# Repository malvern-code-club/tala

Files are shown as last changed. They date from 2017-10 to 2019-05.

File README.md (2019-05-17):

# Tala



A text only portable communication device designed for an apocolypse. This project was a competition entry for [Raspberry Pi Pioneers](https://www.raspberrypi.org/pioneers/).

> Our project ended up winning **'Best Explaination'**. Check out the [announcement blog post](https://www.raspberrypi.org/blog/pioneers-winners-only-you-can-save-us/) ([archive.org](https://web.archive.org/web/20180103014359/https://www.raspberrypi.org/blog/pioneers-winners-only-you-can-save-us/)) for the other winning projects.

> The repository as of when the competition was taking place can be seen on the [`final` tag](https://github.com/malvern-code-club/tala/tree/final).

## talalib.py

talalib.py is a Python module to interact with *most* of the sensors in the Tala
project. You can read the documentation for this module [here](talalib.md).

## Wiring

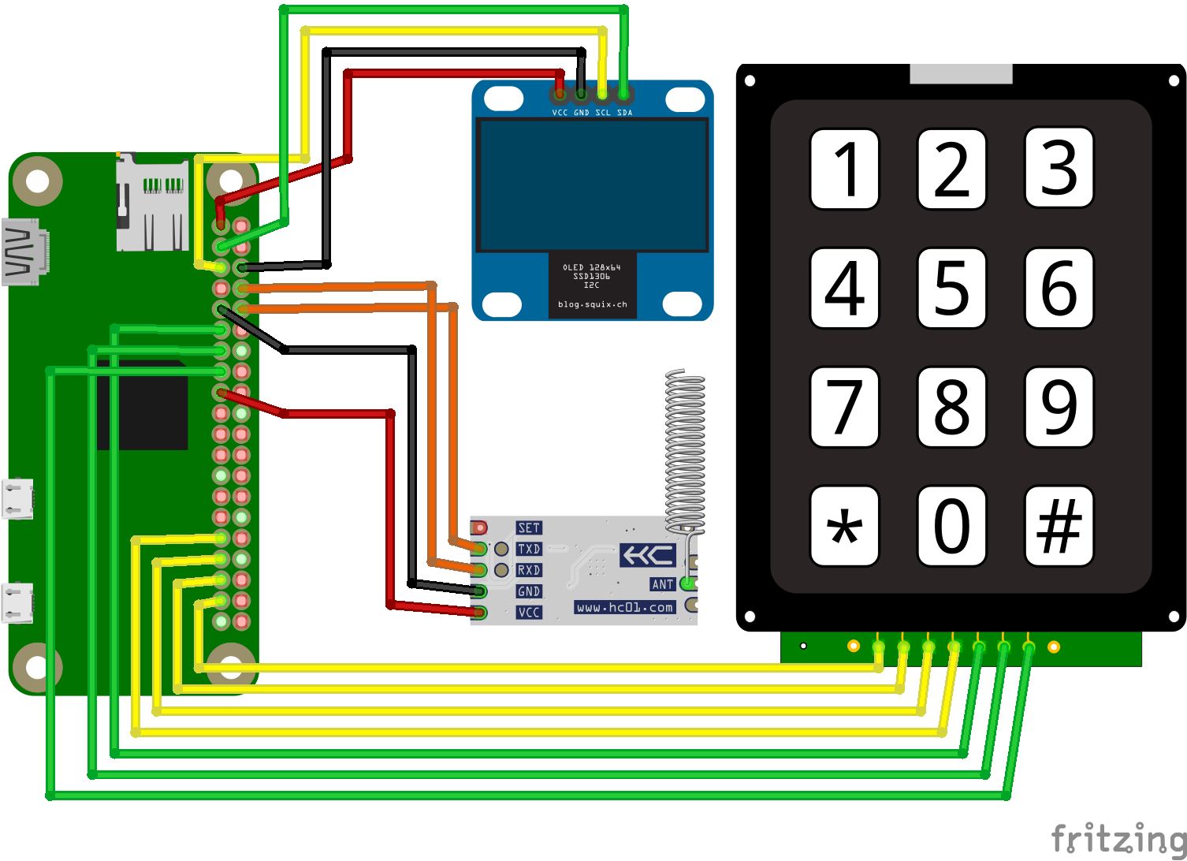
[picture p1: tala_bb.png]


***Wiring for modules may not be as they show in this diagram! We bought 2 OLED
screens and the pinouts on both are different. Be careful!***

### Screen

| Screen | Raspberry Pi |
| --- | --- |
| VCC | 3v3 *(Pin 1)* |
| GND | Ground *(Pin 6)* |
| SCL | SCL *(Pin 5)* |
| SDA | SDA *(Pin 3)* |

### Keypad

| Keypad | Raspberry Pi |
| --- | --- |
| Row 1  | BCM 26 *(Pin 37)* |
| Row 2  | BCM 19 *(Pin 35)* |
| Row 3  | BCM 13 *(Pin 33)* |
| Row 4  | BCM 6 *(Pin 31)*  |
| Col 1  | BCM 17 *(Pin 11)* |
| Col 2  | BCM 27 *(Pin 13)* |
| Col 3  | BCM 22 *(Pin 15)* |

### HC-12 Module

| HC-12 | Raspberry Pi |
| ----- | --- |
| VCC | 3v3 *(Pin 17)* |
| GND | Ground *(Pin 9)*  |
| RXD | BCM 14 *(Pin 8)*  |
| TXD | BCM 15 *(Pin 10)* |

## Installation

1. Start by flashing the latest Raspbian Lite onto an SD card.
2. After it has booted type `sudo raspi-config` to bring up a configuration
window, select `Interfacing Options` -> `I2C` -> `Yes`, then `Interfacing Options`
-> `Serial` -> `No` -> `Yes`. **Rebooting now is not required as we will do it
in the 4th step.**
3. Setup a Wi-Fi connection (you can skip this if you are using ethernet) by
editing this file with the command: `sudo nano /etc/wpa_supplicant/wpa_supplicant.conf`.
Then adding this block of code (changing the placeholders to your network) to the
bottom of the file:
```
network={
  ssid="YOUR NETWORK NAME HERE INSIDE THE QUOTES"
  psk="YOUR NETWORK PASSWORD HERE INSIDE THE QUOTES"
}
```
4. Reboot using the command `sudo reboot`.
5. Start the automatic install script with this command `curl -sSL https://goo.gl/xPTBjq | sudo bash`.
6. Et volia!

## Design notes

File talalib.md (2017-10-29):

# talalib.py
talalib.py is a small python module that allows easy interaction with the sensors used on the Tala project, without the need to know GPIO commands, PIL, etc..

## Supported Modules
- [x] **Screen** - [OLED SSD1306 (128x64)](http://www.ebay.co.uk/itm/I2C-OLED-Display-128X64-0-96-SSD1306-For-Arduino-Raspberry-Pi-ESP8266-etc-/172736606184)
- [x] **Radio Module** - [HC-12 SI4463](http://www.ebay.co.uk/itm/433Mhz-HC-12-SI4463-Wireless-Serial-Port-Module-1000m-Replace-Bluetooth-TE296-/281772656589)
- [x] **Keypad** - [4x3 Keypad](http://www.ebay.co.uk/itm/12-4x3-key-Switch-Membrane-Matrix-KeyPad-Self-Adhesive-Arduino-RPI-PIC-AVR-/131708189209)

## Setup

```python
import talalib
tala = talalib.Tala()
```

## Methods

### `menu(items[List of String])` *[Screen, Keypad]*

Get the user to select from a list of items. The first parameter of the function
is the list of strings to ask the user to select, the output of the function will
be one of the items in the list as a string.

```python
tala.menu(["Item 1", "Item 2", "Item 3"])
# -> "Item 1"
```

### `message(title[String], body[String])` *[Screen, Keypad]*

This shows a message to the user. The first parameter of the function is the
title of the message as a string and the second parameter is the body of the message,
if the body is too long to fit on screen, the user can scroll using the up and
down keys. **The user needs to manually dismiss a message!**

```python
tala.message("Example", "This is an example popup!")
```

Input a title then a body.

### `popup(title[String], body[String])` *[Screen]*

This is similar to the above `message` method, but **does not require user input to
be dismissed** (*the screen needs to be cleared to remove it*). The title parameter
is optional but body is required. **After calling this function, you might want
`tala.singlebutton()` to get user input.**

```python
tala.popup("Popup", "You have mail!")
```

```python
tala.popup(body="You have mail!")
```

### `yn(question[String])` *[Screen, Keypad]*

This uses the above `popup` method and combines it with `singlebutton` to ask the
user a yes/no question. The question parameter is required and needs to be a
string.

```python
tala.yn("Do you like ice cream")
```

### `singlebutton()` *[Keypad]*

This waits for a button on the keypad to be pressed, then returns the button as
a string (0-9, #, \*).

```python
tala.singlebutton()
# -> "1"
```

### `type(wait[Integer]{optional})` *[Screen, Keypad]*

This allows the user to type on the keypad by holding a key to cycle through the
letters and unpressing to type the letter that is currently on the screen. The
user can then press the `#` button to enter the text. An *optional* parameter is
`wait` which is how fast move onto the next letter in the sequence when the button
is held down in seconds (the default is `0.5`). The function returns the message
as a string.

```python
tala.type()
# -> "Hello World!"
```

## `send(message[String])` *[Radio]*

This sends a message via the HC-12 module. The first and only parameter is the
message to send as a string, there is no output.

```python
tala.send("Hello World!")
```

## `waitForReceive()` *[Radio]*

This waits for a message to be received via the HC-12 module. There are no
parameters and the output is the message received as a string.

```python
tala.waitForReceive()
# -> "Hello World!"
```

## `receive()` *[Radio]*

This receives a message from the HC-12 module. There are no parameters and the
output will be the message as a string. The string may be empty, in which case
no message has been received. `waitForReceive()` is the output of this command,
but in a loop.

```python
tala.receive()
# -> "Hello World!"
```

### `cleanup()` *[Keypad]*

This cleans up the GPIO pins. **This should be run when the program quits.**

```python
tala.cleanup()
```

### `clear()` *[Screen]*

This clears the screen.

```python
tala.clear()
```

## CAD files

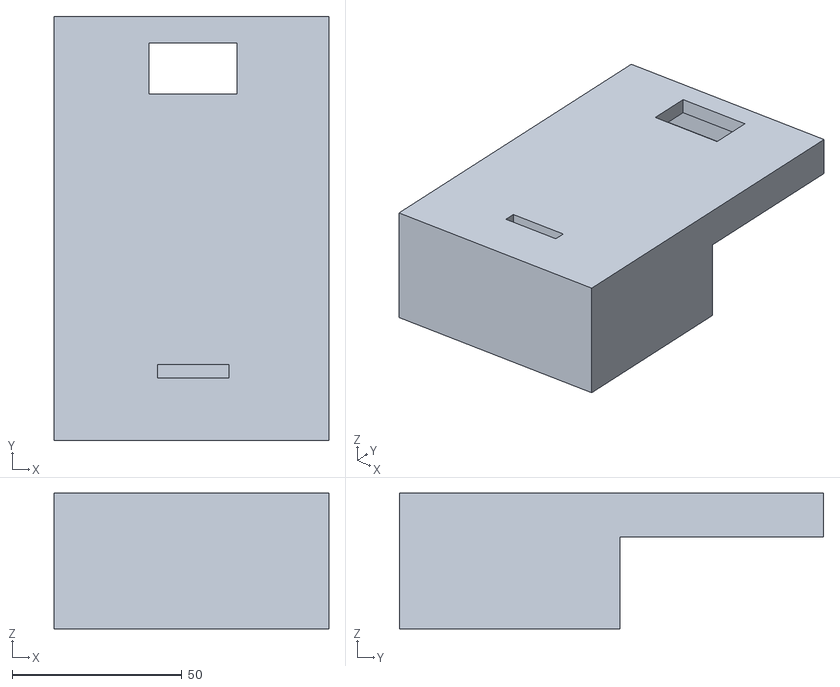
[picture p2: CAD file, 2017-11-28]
Tala Case Lid.stl
81.0 x 125.0 x 40.0

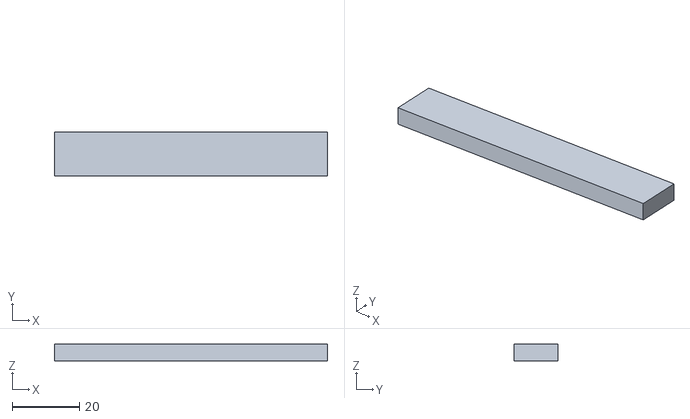
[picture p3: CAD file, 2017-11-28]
Tala Case.stl
81.0 x 13.0 x 4.92

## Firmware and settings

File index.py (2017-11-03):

#!/usr/bin/env python3

import talalib
import sqlite3
import threading
import random
import string
import datetime
import json
import time
import subprocess
import os
import urllib.request
import urllib.error
import sys
import logging
import logging.handlers
import mount
import shutil

REPO_DIR = "/opt/tala/"
STORAGE_DIR = "/opt/"

os.chdir(REPO_DIR)

LOG_NAME = "tala.log"
LOG_FILENAME = STORAGE_DIR + LOG_NAME
LOG_LEVEL = logging.INFO

DB_FILENAME = STORAGE_DIR + "tala.db"

logger = logging.getLogger(__name__)
logger.setLevel(LOG_LEVEL)
handler = logging.FileHandler(LOG_FILENAME)
formatter = logging.Formatter("%(asctime)s %(levelname)-8s %(message)s")
handler.setFormatter(formatter)
logger.addHandler(handler)


class TalaLogger(object):
    def __init__(self, logger, level):
        self.logger = logger
        self.level = level

    def write(self, message):
        if message.rstrip() != "":
            self.logger.log(self.level, message.rstrip())


sys.stdout = TalaLogger(logger, logging.INFO)
sys.stderr = TalaLogger(logger, logging.ERROR)

conn = None
c = None

logger.info("=== STARTED TALA ===")


def setupDb():
    global conn
    global c

    conn = sqlite3.connect(DB_FILENAME)
    c = conn.cursor()

    tables = [
        {
            "name": "memos",
            "columns": "memo_name TEXT, memo_data TEXT"
        },
        {
            "name": "config",
            "columns": "option TEXT, value TEXT"
        }
    ]

    for table in tables:
        c.execute("SELECT name FROM sqlite_master WHERE type='table' AND name=?", [
                  table["name"]])
        data = c.fetchall()

        if len(data) <= 0:  # If table doesn't exist
            logger.info("Creating table " + table["name"] + " with query: CREATE TABLE " + table["name"] + " (" + table["columns"] + ")")
            c.execute("CREATE TABLE " +
                      table["name"] + " (" + table["columns"] + ")")
            conn.commit()


setupDb()


def generateId():
    return "".join(random.choice(string.ascii_uppercase + string.ascii_lowercase + string.digits) for _ in range(6))


def newUdid():
    udid = generateId()
    c.execute("DELETE FROM `config` WHERE option = 'udid'")
    c.execute("INSERT INTO `config` (`option`, `value`) VALUES ('udid', ?)", [udid])
    conn.commit()
    logger.info("Created new Unique Device ID: " + udid + ".")

def encode(data):
    data = json.dumps(data) #Json dump message
    return(data)
def decode(data):
    data = json.loads(data) #Load from json
    return(data)

def restart_tala():
     tala.popup("Updated", "Update was successful! Tala will now restart in 3 seconds...")
     time.sleep(3)
     tala.clear()
     subprocess.call(["/etc/init.d/tala.sh", "restart"])

c.execute("SELECT * FROM `config` WHERE `option` = 'udid'")
if c.fetchone() is None:
    newUdid()

c.execute("SELECT `value` FROM `config` WHERE `option` = 'typespeed'")
if c.fetchone() is None:
    c.execute("INSERT INTO `config` (`option`, `value`) VALUES ('typespeed', '0.5')")
    conn.commit()
    logger.info("Set type speed as 0.5 as it hasn't been set.")

tala = talalib.Tala()

tala.clear()

c.execute("SELECT * FROM `config` WHERE `option` = 'name'")
if c.fetchone() is None:
    tala.message("First Run", "You don't have a name set! Why don't you introduce yourself? Press the checkmark button and then use the keys to type your name.")
    time.sleep(0.5)
    c.execute("SELECT `value` FROM `config` WHERE `option` = 'typespeed'")
    typespeed = c.fetchone()
    typespeed = (float(typespeed[0]) if typespeed is not None else 0.5)
    name = tala.type(wait=typespeed)
    if name is not None:
        c.execute("INSERT INTO `config` (`option`, `value`) VALUES ('name', ?)", [name])
        conn.commit()

def recv_data():
        while True:
            msg = tala.receive()
            if not msg == "":
                msg = decode(msg)
                if msg is not None:
                    tala.interrupt = True

                    tala.message("Message", "MESSAGE: " + msg["content"] +
                                 " | SENT: " + msg["timestamp"] +
                                 " | FROM: " + msg["sender"]["name"],
                                 interrupt_bypass=True)

                    tala.interrupt = False


thread_recv_data = threading.Thread(target=recv_data)
thread_recv_data.start()

while True:
    logger.info("Showing main menu")
    choice = tala.menu(["Public Message", "Memo", "Settings", "Power Off"])
    time.sleep(0.5)
    if choice == "Public Message":
        c.execute("SELECT `value` FROM `config` WHERE `option` = 'typespeed'")
        typespeed = c.fetchone()
        typespeed = (float(typespeed[0]) if typespeed is not None else 0.5)
        content = tala.type(wait=typespeed)

        if content is not None:
            msg_id = generateId()

            timestamp = datetime.datetime.utcnow()
            timestamp = timestamp.strftime("%a %-d %b @ %-I:%M:%S")

            c.execute("SELECT `value` FROM `config` WHERE `option` = 'udid'")
            udid = c.fetchone()[0]

            c.execute("SELECT `value` FROM `config` WHERE `option` = 'name'")
            name = c.fetchone()[0]

            message = {
                "content": content,
                "id": msg_id,
                "timestamp": timestamp,
                "sender": {
                    "name": name,
                    "udid": udid
                }
            }

            logger.info("Sending Public Message: " + encode(message))
            
            tala.send(encode(message))
            time.sleep(0.5)
    elif choice == "Memo":
        c.execute("SELECT * FROM memos")
        memos = c.fetchall()
        if len(memos) > 0:
            logger.info("Showing memo menu.")
            memolist = ["New Memo", "Delete Memo"]
            for memo in memos:
                memolist.append(memo[0])
            choice = tala.menu(memolist)
            time.sleep(0.5)
        else:
            logger.info("No memos created, automatically choosing to create new memo.")
            choice = "New Memo"

        if choice == "New Memo":
            tala.popup(body="Input memo title")
            time.sleep(2)
            c.execute("SELECT `value` FROM `config` WHERE `option` = 'typespeed'")
            typespeed = c.fetchone()
            typespeed = (float(typespeed[0]) if typespeed is not None else 0.5)
            memo_name = tala.type(wait=typespeed)
            time.sleep(1)
            tala.popup(body="Input memo text")
            time.sleep(2)
            memo_data = tala.type(wait=typespeed)
            time.sleep(1)
            logger.info("Created new memo with title '" + memo_name + "' and body '" + memo_data + "'")
            c.execute("INSERT INTO memos (memo_name, memo_data) values (?, ?)", [memo_name, memo_data])
            conn.commit()
        """ 
        elif choice == "Delete Memo":
            if len(memos) < 2:
                c.execute("DELETE FROM memos WHERE memo_name = ?", [choice])
            else:
                choice = tala.menu(memos)
                time.sleep(0.5)
                if choice == "empty":
                    pass
                elif choice is None:
                    pass
                else:
                    c.execute("DELETE FROM memos WHERE memo_name = ?", [choice])
                    conn.commit()
        """
        else:
            c.execute("SELECT memo_data FROM memos WHERE memo_name = ?", [choice])
            memo_data = c.fetchone()
            tala.message(choice, memo_data[0])
            time.sleep(0.5)
    elif choice == "Settings":
        while True:
            choice = tala.menu(["Change Name", "Change Type Speed", "Reset Device ID", "Clear Data", "Update Tala", "Save Log to USB", "Exit Options"])
            if choice == "Reset Device ID":
                time.sleep(0.5)
                result = tala.yn("Are you sure")
                if result:
                    newUdid()
                    tala.message("Reset UDID", "Device ID regenerated!")
                    time.sleep(1)
                elif result is None:
                    pass
                elif not result:
                    tala.message("Reset UDID", "No changes made.")
                    time.sleep(1)
            elif choice == "Change Type Speed":
                time.sleep(1)
                c.execute("SELECT `value` FROM `config` WHERE `option` = 'typespeed'")
                typespeed = c.fetchone()
                typespeed = (typespeed[0] if typespeed is not None else "0.5")
                result = tala.yn("Type speed is " + typespeed + ". Change")
                if result:
                    tala.popup(body="Please insert new type speed (seconds)")
                    time.sleep(1.5)
                    c.execute("SELECT `value` FROM `config` WHERE `option` = 'typespeed'")
                    typespeed = c.fetchone()
                    typespeed = (float(typespeed[0]) if typespeed is not None else 0.5)
                    newtypespeed = tala.type(wait=typespeed)
                    typespeedfloat = None
                    try:
                        typespeedfloat = float(newtypespeed)
                    except ValueError:
                        tala.message("Type Speed", "Failed to update type speed because the inputted value was not a number!")

                    if typespeedfloat is not None:
                        c.execute("UPDATE `config` SET `value` = ? WHERE `option` = 'typespeed'", [typespeedfloat])
                        conn.commit()
                        tala.message("Type Speed", "Your type speed has been changed from " + str(typespeed) + " to " + newtypespeed + "!")
            elif choice == "Change Name":
                time.sleep(0.5)
                c.execute("SELECT `value` FROM `config` WHERE `option` = 'name'")
                name = c.fetchone()[0]
                result = tala.yn("Current name is " + name + ". Change")
                if result:
                    tala.popup(body="Please type new name")
                    time.sleep(1)
                    c.execute("SELECT `value` FROM `config` WHERE `option` = 'typespeed'")
                    typespeed = c.fetchone()
                    typespeed = (float(typespeed[0]) if typespeed is not None else 0.5)
                    newname = tala.type(wait=typespeed)
                    if newname is not None:
                        c.execute("UPDATE `config` SET `value` = ? WHERE `option` = 'name'", [newname])
                        conn.commit()
                        tala.message("Changed", "Your name has been changed from " + name + " to " + newname + "!")
            elif choice == "Clear Data":
                time.sleep(0.5)
                result = tala.yn("Are you sure")
                if result is not None:
                    if result:
                        logger.info("Deleting database...")
                        os.remove(DB_FILENAME)
                        tala.popup("Purging...", "Database purged!")
                        time.sleep(2)
                        tala.popup("Purging...", "Recreating Database...")
                        logger.info("Setting up database...")
                        setupDb()
                        tala.message("Purged", "Successfully cleared data.")
                        time.sleep(1)
                        logger.info("Database purge complete!")
                    elif not result:
                        tala.message("Alert", "No changed made.")
                        time.sleep(1)
            elif choice == "Save Log to USB":
                time.sleep(1)
                result = tala.yn("Save log to usb")
                if result is not None:
                    if result:
                        tala.message("Update", "Please PLUG IN your USB drive to save log to then press the checkmark to continue.")

                        devices = mount.list_media_devices()

                        logger.info(str(len(devices)) + " device(s) found.")

                        device = None

                        if len(devices) <= 0:
                            tala.message("Failure", "Couldn't detect any USB drives.")
                        elif len(devices) == 1:
                            tala.popup("Update", "Only 1 drive found, using that one.")
                            time.sleep(2)
                            device = devices[0]
                        else:
                            tala.popup(body="Select a drive to save to")
                            time.sleep(2)
                            tala.menu(devices)

                        if device is not None:
                            logger.info("Using device " + device)

                            mount.mount(device)

                            if mount.is_mounted(device):
                                files = []

                                for filename in os.listdir(mount.get_media_path(device)):
                                    path = os.path.join(mount.get_media_path(device), filename)
                                    if os.path.isfile(path):
                                        files.append(filename)

                                tala.popup("Copying...", "Copying log file...")
                                logger.info("Copying file from " + LOG_FILENAME + " to " + os.path.join(mount.get_media_path(device), LOG_NAME) + "...")
                                shutil.copy(LOG_FILENAME, os.path.join(mount.get_media_path(device), LOG_NAME))
                                logger.info("Copy complete!")
                                tala.popup("Copyied", "Copy complete!")
                                time.sleep(2)

                            mount.unmount(device)
            elif choice == "Update Tala":
                time.sleep(0.5)
                result = tala.yn("Are you sure you'd like to update")
                if result is None:
                    pass
                elif result:
                    tala.message("Information", "Tala will update even if there's no new version. On the next screen select a way to update.")
                    choice = tala.menu(["Via Internet", "Via USB"])
                    if choice == "Via Internet":
                        tala.popup("Updating...", "Checking internet connection...")
                        # Check for connection
                        connection = False
                        try:
                            urllib.request.urlopen("http://216.58.192.142", timeout=1)
                            connection = True
                        except urllib.error.URLError as e:
                            connection = False

                        if connection:
                            tala.popup("Updating...", "Preparing for update...")
                            if os.path.exists(REPO_DIR + "updatetest"):
                                logger.info("Deleting `updatetest` file")
                                os.remove(REPO_DIR + "updatetest")
                            else:
                                logger.info("There is no `updatetest` file, updating anyway.")

                            tala.popup("Updating...", "Please wait while updating...")

                            # This should update tala from github (in theory)
                            p = subprocess.Popen(["git", "fetch", "--all"], cwd=REPO_DIR)
                            p.wait()
                            p = subprocess.Popen(["git", "reset", "--hard", "origin/master"], cwd=REPO_DIR)
                            p.wait()

                            if os.path.exists(REPO_DIR + "updatetest"):
                                logger.info("`updatetest` file exists. Update successful.")

                                tala.popup("Updating...", "Changing file permissions...")
                                subprocess.call(["chmod", "755", REPO_DIR + "index.py"])
                                tala.popup("Updating...", "Installing Python modules...")
                                p = subprocess.Popen(["python3", "-m", "pip", "install", "-r", "requirements.txt"], cwd=REPO_DIR)
                                p.wait()
                                tala.popup("Updating...", "Updating daemon script...")
                                subprocess.call(["cp", REPO_DIR + "tala.sh", "/etc/init.d"])
                                subprocess.call(["chmod", "755", "/etc/init.d/tala.sh"])

                                restart_tala()
                                break
                            else:
                                logger.info("`updatetest` file doesn't exist. Update unsuccessful.")
                                tala.message("Update", "Update was unsuccessful. You could try updating via USB.")
                        else:
                            logger.info("Couldn't connect to the internet for update")
                            tala.message("Error", "Failed to update, couldn't connect to the internet")
                    elif choice == "Via USB":
                        tala.message("Update", "Please PLUG IN your USB drive to update from then press the checkmark to continue.")

                        devices = mount.list_media_devices()

                        logger.info(str(len(devices)) + " device(s) found.")

                        device = None

                        if len(devices) <= 0:
                            tala.message("Failure", "Couldn't detect any USB drives.")
                        elif len(devices) == 1:
                            tala.popup("Update", "Only 1 drive found, using that one.")
                            time.sleep(2)
                            device = devices[0]
                        else:
                            tala.popup(body="Select a drive to copy from")
                            time.sleep(2)
                            tala.menu(devices)

                        if device is not None:
                            logger.info("Using device " + device)

                            mount.mount(device)

                            if mount.is_mounted(device):
                                files = []

                                for filename in os.listdir(mount.get_media_path(device)):
                                    path = os.path.join(mount.get_media_path(device), filename)
                                    if os.path.isfile(path):
                                        files.append(filename)

                                if len(files) <= 0:
                                    tala.message("Failure", "No files found on drive!")
                                    logger.info("No files found on " + device + "!")
                                else:
                                    files.append("Exit")
                                    choice = tala.menu(files)
                                    if choice is None:
                                        pass
                                    elif choice != "Exit":
                                        yn = tala.yn("Copy & Overwrite " + choice)
                                        if yn:
                                            logger.info("Copying file from " + os.path.join(mount.get_media_path(device), choice) + " to " + os.path.join(REPO_DIR, choice) + "...")
                                            shutil.copy(os.path.join(mount.get_media_path(device), choice), os.path.join(REPO_DIR, choice))
                                            logger.info("Copy complete!")
                                            tala.popup("Updated", "Updated file " + choice + "!")
                                            time.sleep(0.5)
                                            restart = tala.yn("Restart")
                                            if restart:
                                                restart_tala()
                            else:
                                logger.info("Problem mounting drive " + device)
                                tala.message("Failure", "Problem mounting " + device + "!")

            elif choice == "Exit Options":
                break
    elif choice == "Power Off":
        time.sleep(0.5)
        option = tala.yn("Are you sure you'd like to power off")
        if option:
            logger.info("=== POWERING OFF DEVICE ===")
            tala.popup(body="Device shutting down. Wait up to 10s before removing power.")
            tala.cleanup()
            subprocess.call(["sudo", "halt"])
            break

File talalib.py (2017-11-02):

import time

import serial

import Adafruit_SSD1306

from PIL import Image
from PIL import ImageDraw
from PIL import ImageFont

import textwrap

import RPi.GPIO as GPIO

_FONT_LECO_PATH = "/opt/tala/leco1976.ttf"
_FONT_FREEPIXEL_PATH = "/opt/tala/FreePixel.ttf"

class Tala():

    interrupt = False

    def __init__(self):
        # Setup Display
        self.display = Adafruit_SSD1306.SSD1306_128_64(rst=24)

        self.display.begin()
        self.display.clear()
        self.display.display()

        self.width = self.display.width
        self.height = self.display.height

        # Setup Radio
        self.radio = serial.Serial("/dev/serial0", baudrate=9600, timeout=1)

        # Setup Keypad
        GPIO.setmode(GPIO.BCM)

        # Tell the Raspberry Pi that each row on the keypad is an output
        GPIO.setup(26, GPIO.OUT) # row 1
        GPIO.setup(19, GPIO.OUT) # row 2
        GPIO.setup(13, GPIO.OUT) # row 3
        GPIO.setup(6, GPIO.OUT) # row 4

        # Tell the Raspberry Pi that each column on the keypad is an input and
        # should have an (internal) pull down resistor.
        GPIO.setup(17, GPIO.IN, pull_up_down=GPIO.PUD_DOWN) # col 1
        GPIO.setup(27, GPIO.IN, pull_up_down=GPIO.PUD_DOWN) # col 2
        GPIO.setup(22, GPIO.IN, pull_up_down=GPIO.PUD_DOWN) # col 3

        # Turn keypad rows off.
        GPIO.output(26, GPIO.LOW)
        GPIO.output(19, GPIO.LOW)
        GPIO.output(13, GPIO.LOW)
        GPIO.output(6, GPIO.LOW)

    def keypad_row(self, row):
        if row == 1:
            GPIO.output(26, GPIO.HIGH)
            GPIO.output(19, GPIO.LOW)
            GPIO.output(13, GPIO.LOW)
            GPIO.output(6, GPIO.LOW)
        if row == 2:
            GPIO.output(26, GPIO.LOW)
            GPIO.output(19, GPIO.HIGH)
            GPIO.output(13, GPIO.LOW)
            GPIO.output(6, GPIO.LOW)
        if row == 3:
            GPIO.output(26, GPIO.LOW)
            GPIO.output(19, GPIO.LOW)
            GPIO.output(13, GPIO.HIGH)
            GPIO.output(6, GPIO.LOW)
        if row == 4:
            GPIO.output(26, GPIO.LOW)
            GPIO.output(19, GPIO.LOW)
            GPIO.output(13, GPIO.LOW)
            GPIO.output(6, GPIO.HIGH)

    def singlebutton(self, wait=0.05, interrupt_bypass=False):
        key = ""

        # Loop while we haven't got a key
        while key == "":
            # Turn on row 1 but turn off every other row
            self.keypad_row(1)
            # If the first column is turned on we know that the first
            # button has been pressed and so on.
            if GPIO.input(17):
                key = "1"
            if GPIO.input(27):
                key = "2"
            if GPIO.input(22):
                key = "3"

            self.keypad_row(2)
            if GPIO.input(17):
                key = "4"
            if GPIO.input(27):
                key = "5"
            if GPIO.input(22):
                key = "6"

            self.keypad_row(3)
            if GPIO.input(17):
                key = "7"
            if GPIO.input(27):
                key = "8"
            if GPIO.input(22):
                key = "9"

            self.keypad_row(4)
            if GPIO.input(17):
                key = "*"
            if GPIO.input(27):
                key = "0"
            if GPIO.input(22):
                key = "#"

            if self.interrupt and not interrupt_bypass:
                print("Interrupting singlebutton(). Interrupt is " + str(self.interrupt) + ", Bypass is " + str(interrupt_bypass))
                return None

            time.sleep(wait)
        return key

    def type_numbers(self, wait=0.05, interrupt_bypass=False):
        doloop = True
        message = ""
        key = ""

        while doloop:
            self.keypad_row(1)
            if GPIO.input(17):
                key = "1"
            if GPIO.input(27):
                key = "2"
            if GPIO.input(22):
                key = "3"

            self.keypad_row(2)
            if GPIO.input(17):
                key = "4"
            if GPIO.input(27):
                key = "5"
            if GPIO.input(22):
                key = "6"

            self.keypad_row(3)
            if GPIO.input(17):
                key = "7"
            if GPIO.input(27):
                key = "8"
            if GPIO.input(22):
                key = "9"

            self.keypad_row(4)
            if GPIO.input(17):
                key = "*"
            if GPIO.input(27):
                key = "0"
            if GPIO.input(22):
                doloop = False
                key = ""
            message = message + key

            if self.interrupt and not interrupt_bypass:
                print("Interrupting type_numbers(). Interrupt is " + str(self.interrupt) + ", Bypass is " + str(interrupt_bypass))
                return None

            time.sleep(wait)
        return message

    def type(self, wait=0.5, interrupt_bypass=False):
        # Make a new image/canvas with the width and height of the screen.
        image = Image.new("1", (self.width, self.height))
        # Make a new draw variable which draws shapes/text to the screen.
        draw = ImageDraw.Draw(image)

        # Define the fonts
        bigfont = ImageFont.truetype(_FONT_LECO_PATH, 45)
        font = ImageFont.truetype(_FONT_FREEPIXEL_PATH, 14)

        # Define the characters to cycle for each key on the keypad
        # Special:
        #   _ = Space
        #   <- = Backspace
        keypadkeys = {
            "1": ["1"],
            "2": ["a", "b", "c", "2"],
            "3": ["d", "e", "f", "3"],
            "4": ["g", "h", "i", "4"],
            "5": ["j", "k", "l", "5"],
            "6": ["m", "n", "o", "6"],
            "7": ["p", "q", "r", "s", "7"],
            "8": ["t", "u", "v", "8"],
            "9": ["w", "x", "y", "z", "9"],
            "0": ["_", "0"],
            "*": ["<-", ".", ",", "!", "?"]
        }

        doloop = True
        message = ""
        keybefore = ""
        key = ""
        currentletter = ""

        while doloop:
            key = ""

            self.keypad_row(1)
            if GPIO.input(17):
                key = "1"
            if GPIO.input(27):
                key = "2"
            if GPIO.input(22):
                key = "3"

            self.keypad_row(2)
            if GPIO.input(17):
                key = "4"
            if GPIO.input(27):
                key = "5"
            if GPIO.input(22):
                key = "6"

            self.keypad_row(3)
            if GPIO.input(17):
                key = "7"
            if GPIO.input(27):
                key = "8"
            if GPIO.input(22):
                key = "9"
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

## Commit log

2017-10-07 Added Fritzing Wiring Diagram
    [tala.fzz]
2017-10-09 Added Radio Support and Added Comments to Talalib
    [tala.fzz]
2017-10-13 Additions
    -Added support for PIN changing
    -Added the starting point for recv_data
    -Added setup for SQLite
2017-10-13 Are you sure you want to power off?
    Added an "are you sure you want to power off" option.
    Also, it now turns it off fully.
2017-10-15 Fixed some more bugs
    [index.py]
2017-10-15 Fixed Errors with Zextral's Function
    [talalib.py]
2017-10-15 Sorta getting bored from fixing problems
    [talalib.py]
2017-10-15 Fixed Memos not saving
    [index.py]
2017-10-17 Finished Public Messaging + Additions
    -Finished Public Messaging
    This may not work. I can't test it on school computers. Hopefully it should though.
    -Added the ability to delete memos
    -Started to look at the pin system
    [index.py]
2017-10-20 # Button now used for dismissing message box
2017-10-29 Swapped buttons on yn()
    [talalib.py]
2017-10-29 Added Logging & Power off prompt
2017-10-29 Implemented Device ID
2017-10-29 Fixed UDID generation with random
    [index.py]
2017-10-29 Removed Message Thread Temporarily
2017-10-29 Fixed Message ID generation
    [index.py]
2017-10-29 Fixed message timestamp generation
    [index.py]
2017-10-29 Fixed message sending and removed device PIN
    [index.py]
2017-10-29 Fixed Internet Check (probably)
    [index.py]
2017-10-29 Fixed Install Script + Bugs with /opt/ install
    [talalib.py]
2017-10-29 Switched to Popen instead of call
2017-10-29 Cleaned Repo & Fixed Update Procedure
    [index.py]
2017-10-29 Added more messages and fixed bugs
    [index.py]
2017-10-29 Fixed usb update, change name and send name in message
    [index.py]
2017-10-30 Replaced sleeps 1 with 0.5 and changed restart
    Restart is now in a function and clears the screen before restarting
    time.sleep(1) -> time.sleep(0.5)
    [index.py]
2017-10-31 Hopefully fixed message receiving
    [index.py, talalib.py]
2017-10-31 Added Interrupt Bypassing
2017-10-31 Added interrupt debugging messages
2017-11-01 popup() interrupt fix
2017-11-02 Fixed type speed error
    [index.py]
2017-11-02 Fixed type error typo
    [index.py]
2017-11-03 Updated index.py
    -Fixed an issue when trying to send a message with no content.
    [index.py]
2017-11-03 Some fixes and removals
    -Removed (commented out) deletion of functions as I cannot get them to work.
    -Fixed issues with Joe's (https://github.com/zextral) ~~bad coding~~ restart function.
    [index.py]
2017-11-28 Added 3D printer files
    [Tala Case Lid.stl, Tala Case.stl]
